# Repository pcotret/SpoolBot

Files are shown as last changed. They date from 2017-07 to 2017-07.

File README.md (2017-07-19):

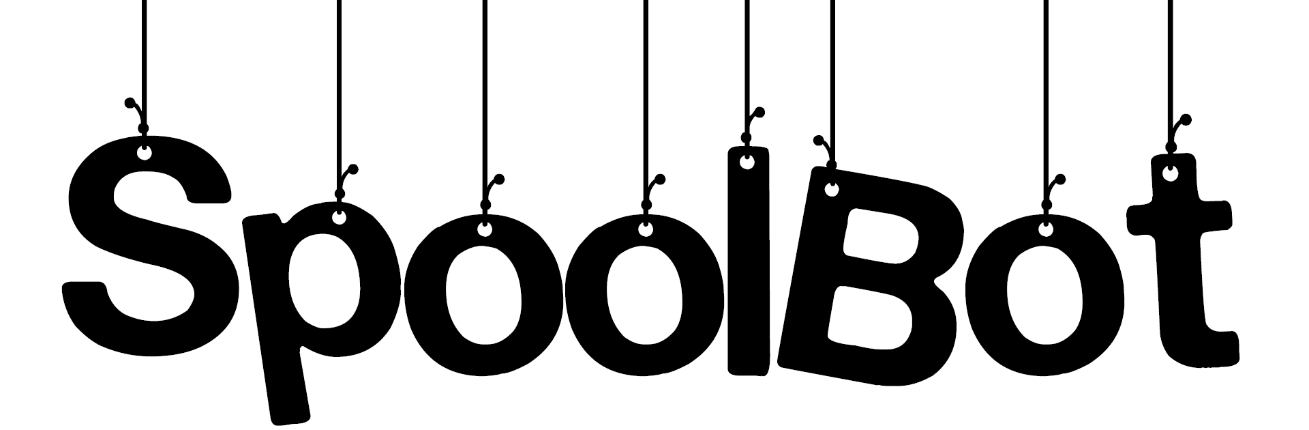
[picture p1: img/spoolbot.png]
spoolbot

# How to create a filament counter for a 3D printer for a few bucks
### Vladimir Béraud-Peigné, Eric Gastineau, Marie Xérès
CentraleSupélec, Rennes campus, 2016/2017

This project has been realized by Vladimir Béraud-Peigné, Eric Gastineau and Marie Xérès (1st year students 16/17 at CentraleSupélec, Rennes campus) for a short-term project under the supervision of Dr. Pascal Cotret.

## Goals of this project
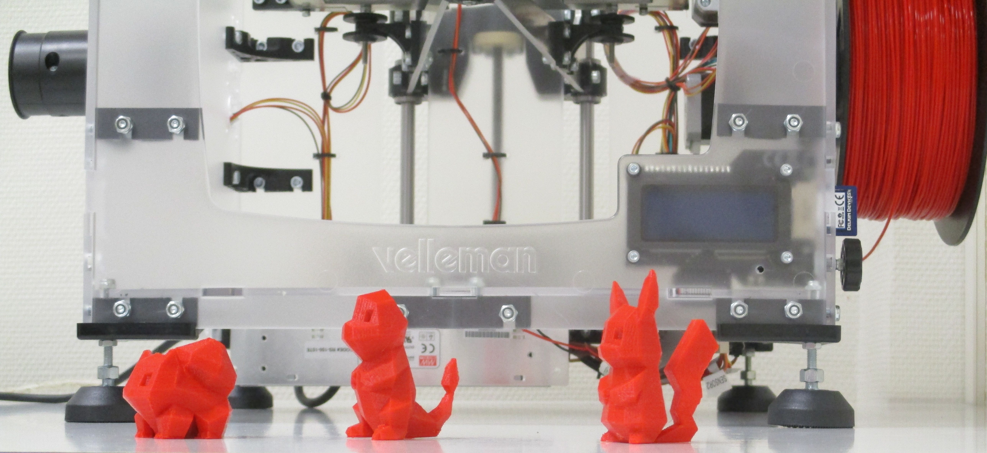
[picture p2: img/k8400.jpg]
k8400

Well, the basic idea of this project came from a little problem. We have a small fablab room with a Velleman K8400 3D printer. Unfortunately, this printer does not have a filament counter:

* We cannot know exactly how much filament has been used (in terms of length).
* As a consequence, we do not how much filament remains on the spool.

By browsing the Internet, we found a cool solution: https://www.hackster.io/binsun148/smart-3d-printer-filament-counter-filamentbot-383ac8

* It is cheap (based on a good old PS/2 mouse).
* It is quite well documented.

However, as this is a student project, the idea was not only to follow a tutorial but to understand how such a project can be achieved. This tutorial will show how we built our own SpoolBot!

## How does a mechanical mouse work?
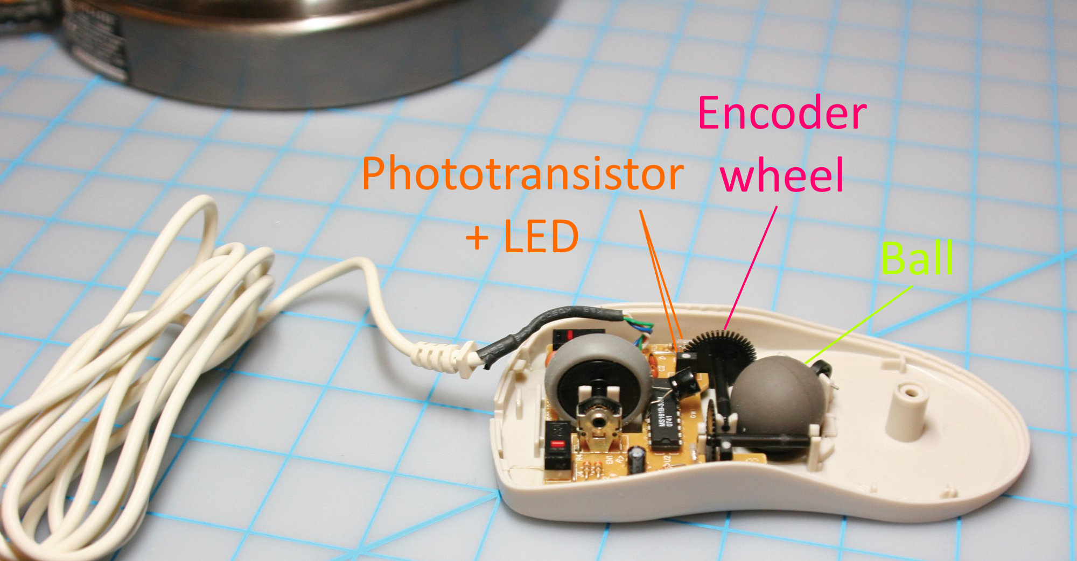
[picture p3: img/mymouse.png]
souris


A good old computer mouse is based on a ball causing the rotation of a small cylinder.This cylinder has an encoder wheel (drilled with several holes) at one of its ends. This wheel is placed between a phototransistor and a LED: counting pulses received by the phototransistor can be used to measure the distance traveled by the mouse ball.

Detecting the ball direction is a bit more tricky... In fact, there are two photo transistors slightly shifted. When we get through a hole of the wheel encoder, we get two detections (one for each transistor). Depending on which one comes first, we can guess the direction of the mouse.

## PS2 protocol

A computer mouse is a device giving ```[X,Y]``` coordinates of a movement and information about ```[left/right]``` clicks. Such information are transmitted through a synchronous serial link with a 9600bd/s baudrate: each frame is based on a classic ```8p1``` layout (8 data bits, 1 parity bit and 1 stop bit).

By default, a PS/2 computer mouse works with a 200 CPI (*Counts Per Inch*) resolution leading to 8 counts/mm (step is 125µm). Movements are coded on 8 bits for a distance of 3.2cm. The mouse is able to transmit up to 40 movements per second which allows to encode movements up to 2m/s (we think that’s quite enough, even for a hardcore gamer!).

Transmitted data is based on 8-bit words (see diagram below), with a start bit (set to 0) as a preamble. Data words are ended by a parity bit and a stop bit (set to 1). The whole message is coded on 11 bits.

ps2

The mouse transmits information in 3 frames spaced by 350 µs: frames are 3.6ms long and are spaced by 6.4ms at least. As a consequence, the mouse is able to transmit up to 100 frames per second.

full

The first frame word contains the following information:

* ```L```: left button (active at 1).
* ```R```: right button (active at 1).
* ```Xs```: direction of the horizontalmoving (1 for left, 0 for right).
* ```Ys```: direction of the verticalmoving (1 for low, 0 for high).
* ```Xv```: overflow in X.
* ```Yv```: overflow in Y.

The two other words transmit the moving value:
* ```X[0..7]```: moving along the horizontal axis (positive to the right, negative to the left).
* ```Y[0..7]```: moving along the vertical axis (positive to the bottom, negative to the top).

## PS/2 decoding on Arduino

We were quite lucky, some nice people have already implemented a PS/2 library: https://playground.arduino.cc/ComponentLib/Ps2mouse
The ```mouse.txt``` file contains an Arduino sketch helping us to create a sketch suiting our needs. Let’s focus on the ```mouse_read()``` method:

```C++
char mouse_read(void)
{
  char data=0x00;
  int i;
  char bit=0x01;
  // Set clk and data lines to high
  gohi(MCLK);
  gohi(MDATA);
  // Wait for the first clock cycle
  delayMicroseconds(50);
  while(digitalRead(MCLK)==HIGH);
  delayMicroseconds(5);
  while(digitalRead(MCLK)==LOW);
  // For each clock rising edge, get the data bit
  for(i=0;i<8;i++)
  {
	while(digitalRead(MCLK)==HIGH);
    	if(digitalRead(MDATA)==HIGH)
	{
	  data=data|bit;
    	}
    	while(digitalRead(MCLK)==LOW);
    	bit=bit<<1;
  }
  // Wait for two clock cycles (parity and stop bits)
  while(digitalRead(MCLK)==HIGH);
  while(digitalRead(MCLK)==LOW);
  while(digitalRead(MCLK)==HIGH);
  while(digitalRead(MCLK)==LOW);
  // Set clock line to low
  golo(MCLK);
  return data;
}
```

## SpoolBot solution
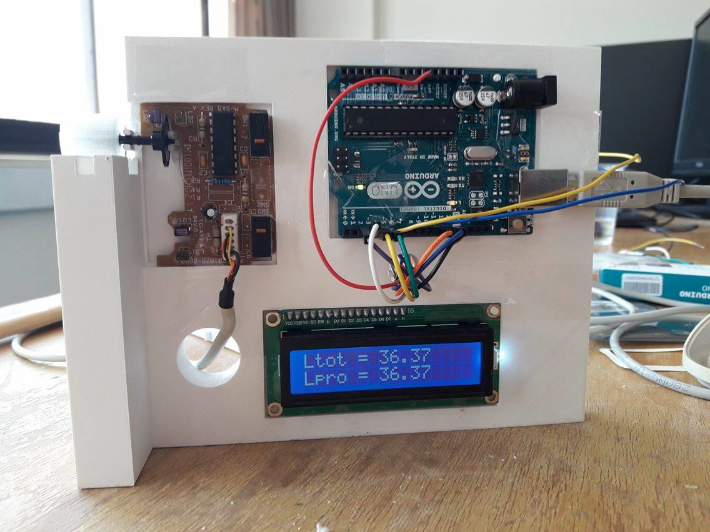
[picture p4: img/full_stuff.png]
full


### Arduino code
See https://github.com/pcotret/SpoolBot/blob/master/docs/spoolbot_code/spoolbot_code.ino

### Wiring diagram
You can also find it at https://github.com/pcotret/SpoolBot/blob/master/docs/fritzing_spoolbot.fzz
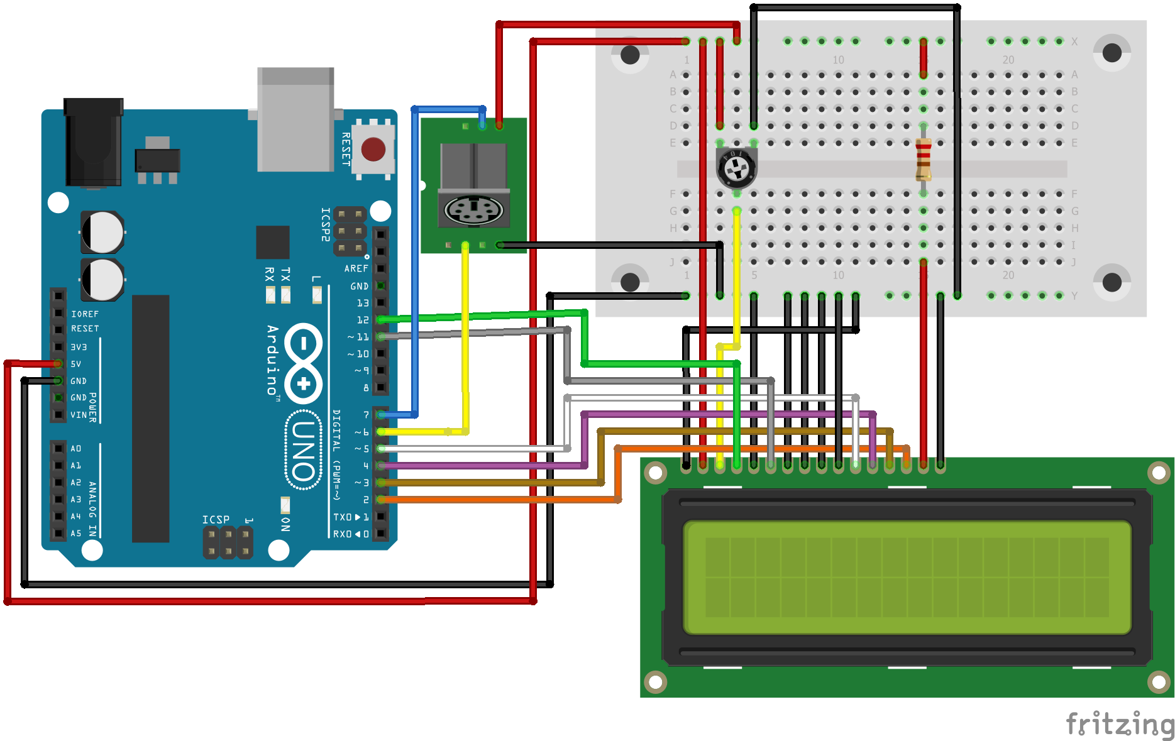
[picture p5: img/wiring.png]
fritzing


### 3D-printed case
To be completed, we need to fix a few things on 3D files.
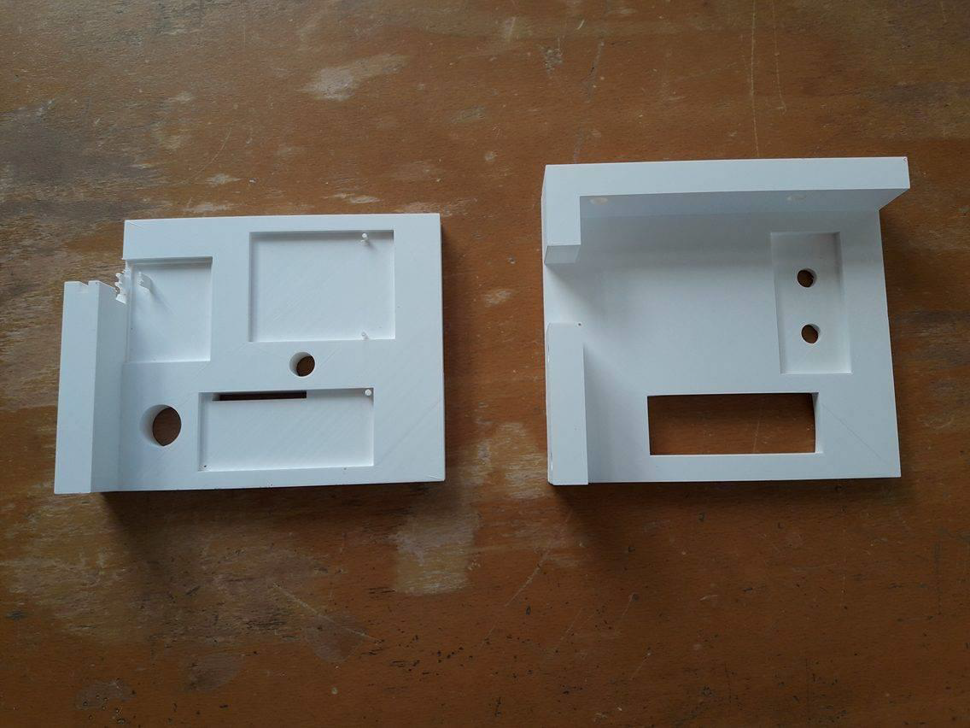
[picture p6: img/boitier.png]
solidworks


## Demonstration video
hello (https://www.youtube.com/watch?v=5DotnpfB1dM)

## References
* http://jerome.hennecart.free.fr/principe_souris.htm
* http://www.rennes.supelec.fr/ren/perso/jweiss/docs/mouse_ps2/souris_ps2.php/
* https://playground.arduino.cc/ComponentLib/Ps2mouse
* https://www.hackster.io/binsun148/smart-3d-printer-filament-counter-filamentbot-383ac8

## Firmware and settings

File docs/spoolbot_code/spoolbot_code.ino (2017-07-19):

// Libraries
#include <LiquidCrystal.h>
#include <ps2.h>

// Initialize the LCD screen
LiquidCrystal lcd(12,11,5,4,3,2);

// Connect the PS/2 mouse: data on pin 6, clock on pin 7
PS2 mouse(7,6);

// Initialize the mouse structure
void mouse_init()
{
  mouse.write(0xff); // Reset byte
  mouse.read();      // Ack byte
  mouse.read();      // Blank byte
  mouse.read();      // Blank byte
  mouse.write(0xf0); // Remote mode byte
  mouse.read();      // Ack byte
}

// Global variables: the mouse position
float x_position=0;
float total_position=0;
float total_length=0;
float current_length=0;
char mouse_state;
char mouse_x;
char mouse_y;

// Setup (executed only once)
void setup()
{
  Serial.begin(9600);// Initialize the serial link	
  mouse_init();
  lcd.begin(16,2); // Set LCD numbers of lines/rows
}

// Main loop (infinite)
void loop()
{
  // Set the LCD position to [0,0]
  lcd.setCursor(0,0);
  // Print the total length of filament used
  lcd.print("Total: ");
  lcd.print(total_length);
  lcd.setCursor(0,1);
  // Print the current length of filament used
  lcd.print("Current: ");
  lcd.print(current_length);
  // Transmit data with the mouse
  mouse.write(0xeb);        // Asking the mouse to send us data
  mouse.read();             // Ignore the acknowledgment bit
  mouse_state=mouse.read(); // Read mouse state
  mouse_x = mouse.read();   // Get X movement
  mouse_y = mouse.read();   // Get Y movement
  // Computing the absolute position
  x_position=x_position+mouse_x;
  current_length=x_position*0.038;
  total_position=total_position+mouse_x;
  total_length=total_position*0.038;
  // Displaying results in the serial monitor
  Serial.print("Current: ");
  Serial.print(current_length);
  Serial.print("Total: ");
  Serial.print(total_length);
  // If left button is pressed, reset the total length
  if(mouse_state&(1<<0))
  {
    Serial.print("Resetting total counter!");
    total_length=0;
    total_position=0;
    lcd.clear();
  }
  // If right button is pressed, reset the current length
  if(mouse_state&(1<<1))
  {
    Serial.print("Resetting current counter!");
    current_length=0;
    x_position=0;
    lcd.clear();
  }
  Serial.println();
}
